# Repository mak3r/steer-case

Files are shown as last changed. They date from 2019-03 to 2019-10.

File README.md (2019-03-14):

# Steer Case
Rancher Logo Shaped case for raspberry pi with battery and other components

* CaseBase.stl - The bottom half of the case for 3D printing
* CaseTop.stl - The top half of the case for 3D printing
* Cattle Case.f3z - The Fusion 360 archive with complete history of the design
* powerboost.brd - The Powerboost board in eagle cad format
* steer.dxf - The Rancher Labs logo ready for extrusion
* tests/ - Various printable test components and openscad files for generating the testmodels

## BOM
* 6 pieces of wire - about 10 cm in length each
* Assorted connectors
  * [Female crimp pins](https://www.pololu.com/product/1930)
  * [1x3 Connector housings](https://www.pololu.com/product/1902)
  * Also I used 1-1x1 and 1-1x2 housing to split the LBO connection from the power wires(search pololu or your favorite electronics vendor)
  * Molex headers and wire housings. [Like these connectors](https://www.mouser.com/Search/Refine?Keyword=538-08-55-0111) and [these housings](https://www.mouser.com/ProductDetail/Molex/22-01-2035?qs=%2Fha2pyFadujIEQkzoGlzi6OdgxxLl5ZwtIU0IZrEPkY%3D)

*I picked up the following from Adafruit but you can get them other places too.*
* [Raspberry Pi 3 - Model B+ - 1.4GHz Cortex-A53 with 1GB RAM](https://www.adafruit.com/product/3775)
* [PowerBoost 1000 Charger - Rechargeable 5V Lipo USB Boost @ 1A - 1000C](https://www.adafruit.com/product/2465)
* [Breadboard-friendly SPDT Slide Switch](https://www.adafruit.com/product/805)
* [Lithium Ion Battery - 3.7v 2000mAh](https://www.adafruit.com/product/2011)
* [0.1" 2x20-pin Strip Right Angle Female Header](https://www.adafruit.com/product/2823)
* [Break-away 0.1" 36-pin strip right-angle male header](https://www.adafruit.com/product/1540)

## Basic Assembly
1. Print the case top and bottom. 
1. Prepare 3 wires for the switch and add connectors. *Note: I found that I needed to use 1 of the molex type connectors for the switch and used a standard 1x3 2.54mm connector for the other end.*
1. Prepare the other 3 wires and connect a 1x3 connector on one end and a 1x2 and a 1x1 on the other ends.
1. Solder a strip of 6 of the right angle male headers to the underside of the powerboost with the open ends facing into the board. The pins should span between Vs and 5v
1. Connect 1-2x20 right angle female header to the Raspberry Pi GPIO - this allows us to keep a low profile
1. Glue the switch into the bottom of the case
1. Conect the switch cable (all 3 wires between 2 1x3 headers - one is molex) to the Vs/EN/GND of the powerboost
1. Connect the other cable with the 1x3 header to the 5v/GND/LBO on the powerboost
1. Connect the 5v and GND wires to pins 4 and 6 on the Raspberry Pi
1. Connect the LBO pin to Pin 12 (or any GPIO you choose) on the Raspberry Pi
1. Glue the switch to the case (you don't have to but I found it's easier to keep in place with a dot of glue)
1. Connect the other side of the Vs/EN/GND cable to the switch
1. Place the battery in the steer head
1. Connect the battery
1. Power off it it is powered on
1. Insert an SD card into the Raspberry Pi. Be sure you can access the OS before closing the case. 
1. Insert the Raspberry Pi into the case base
1. Close it up

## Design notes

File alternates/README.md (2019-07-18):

# CaseTop-see-pi.stl
Designed with a thinner layer near the RaspberryPi insert.
Print with a clear filament to see through the top to the Rpi device.

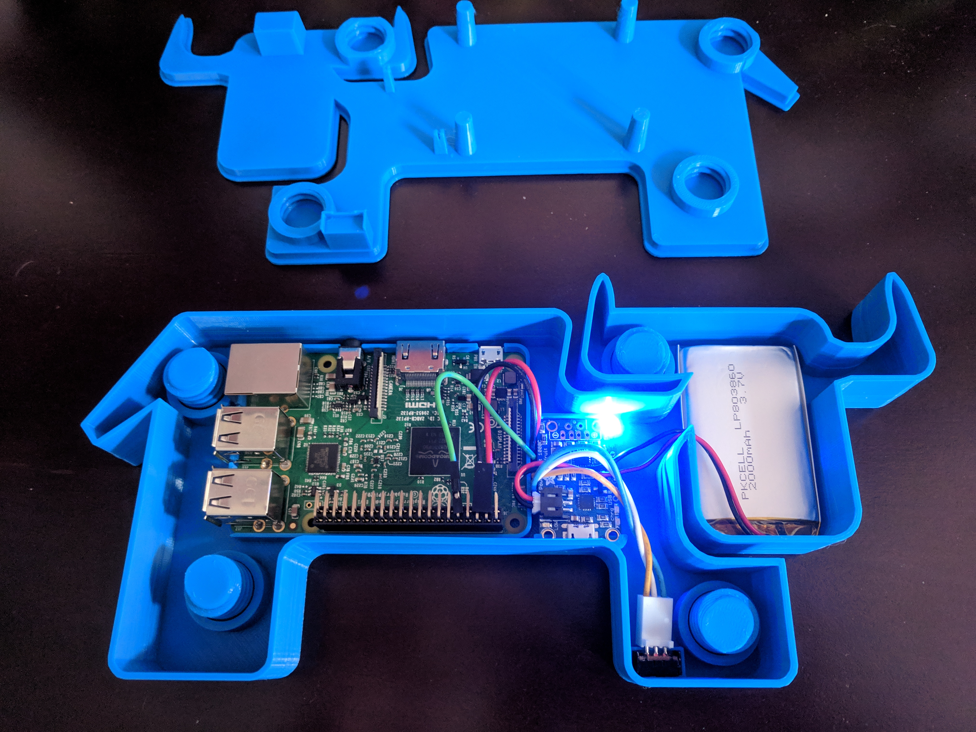
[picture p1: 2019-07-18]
images/powered_on.jpg

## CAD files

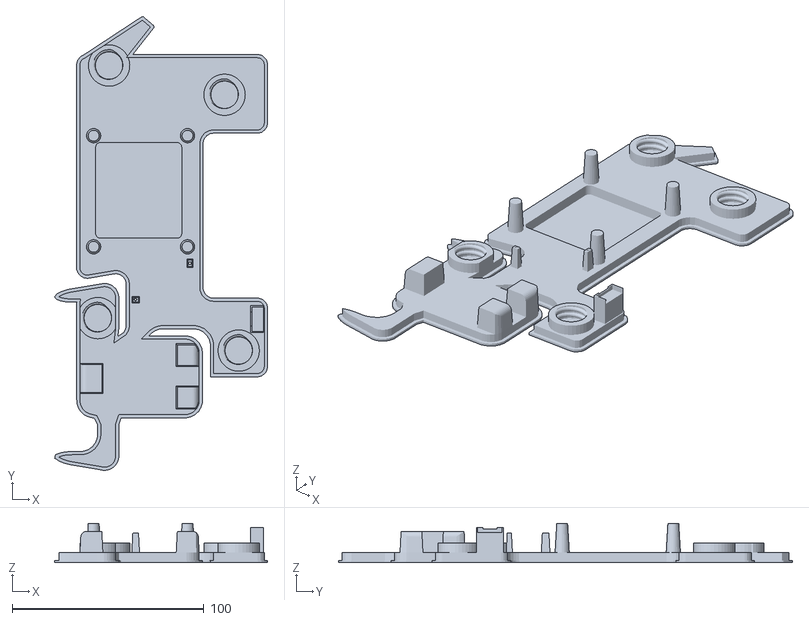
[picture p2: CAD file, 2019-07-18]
alternates/CaseTop-see-pi.stl
111.2 x 237.0 x 20.5

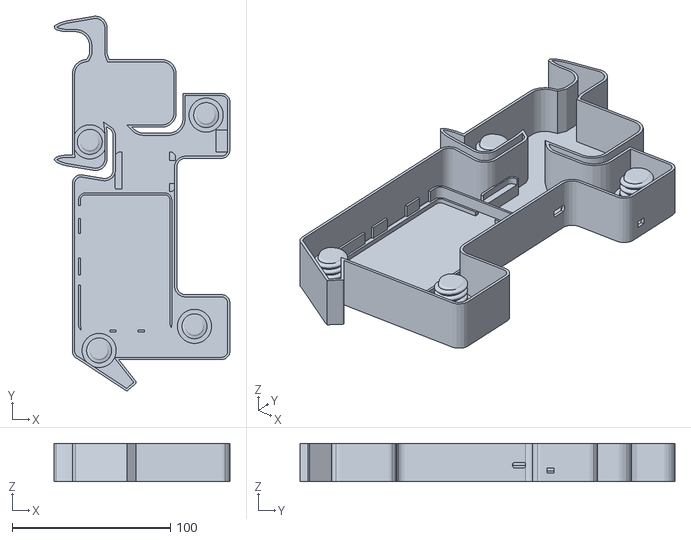
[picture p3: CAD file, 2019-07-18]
CaseBase.stl
111.2 x 237.0 x 24.3

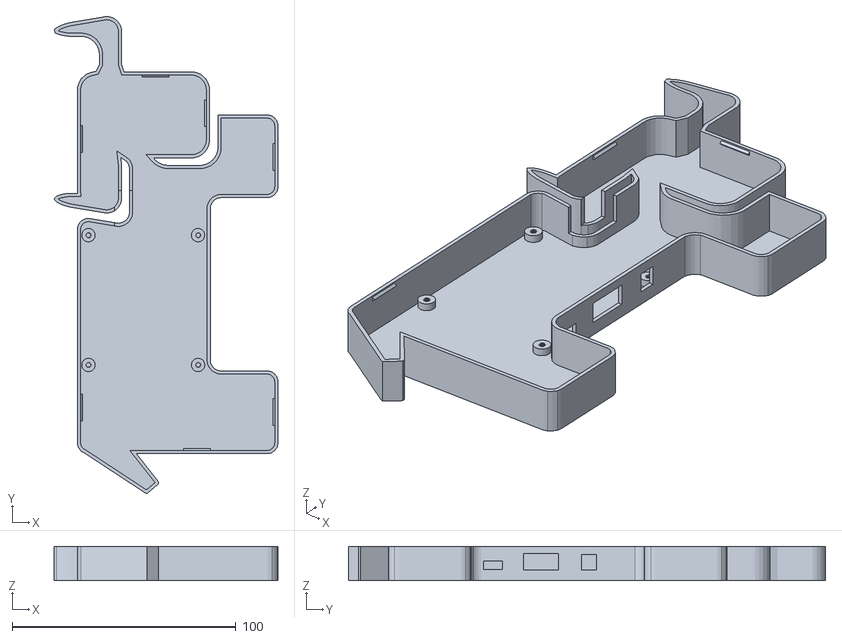
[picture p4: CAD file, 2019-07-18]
plug-in/RPi3Aplus/Base.stl
100.1 x 213.3 x 15.3

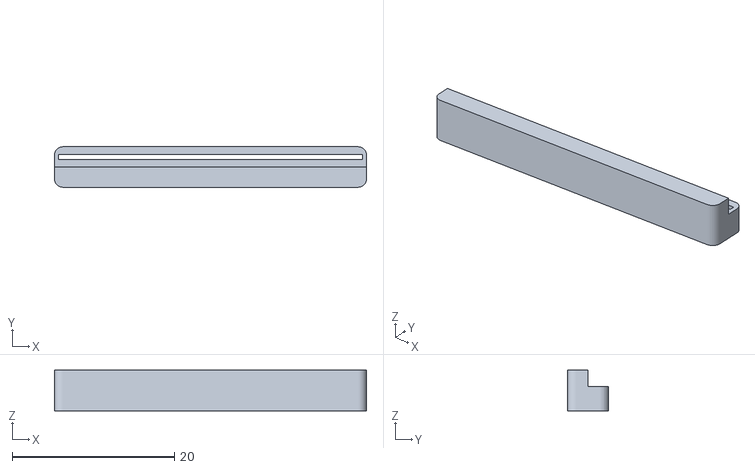
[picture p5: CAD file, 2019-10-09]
plug-in/RPi3Aplus/RevB/UPS spacer.stl
38.5 x 5.00 x 5.00

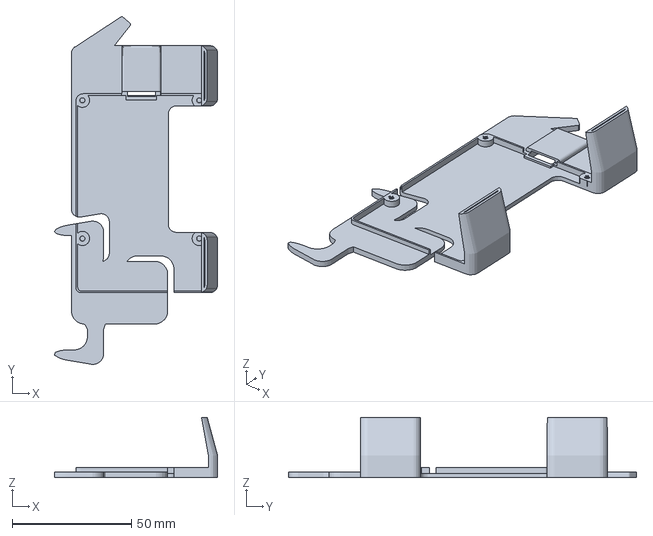
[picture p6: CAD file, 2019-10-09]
plug-in/StandingCase/StandingCase.zip.amf
68.5 x 146.0 x 25.2 mm

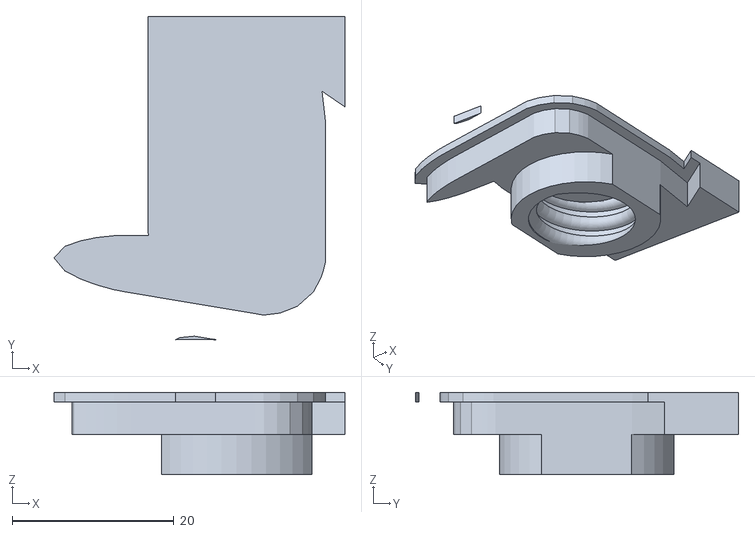
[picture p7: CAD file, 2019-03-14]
tests/case-top-thread-test.stl
36.0 x 40.0 x 10.2

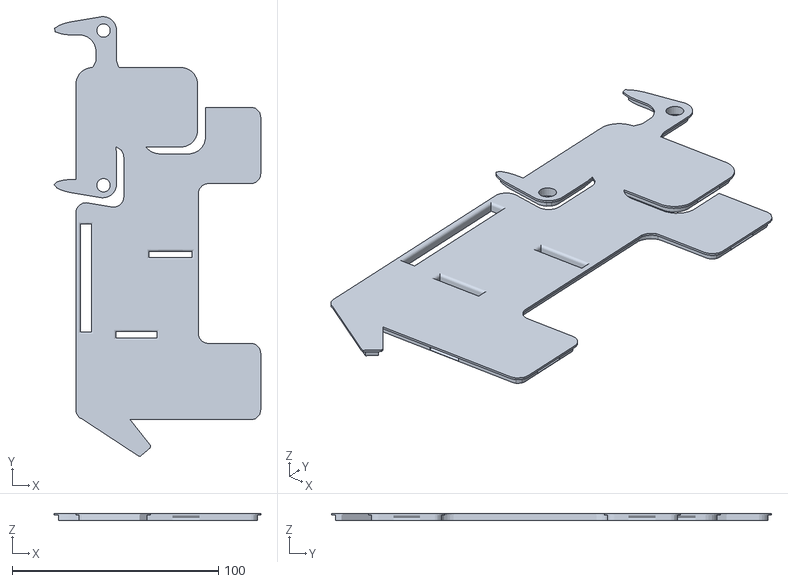
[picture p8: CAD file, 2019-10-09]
plug-in/RPi3Aplus/RevB/Top.stl
100.1 x 213.3 x 3.25

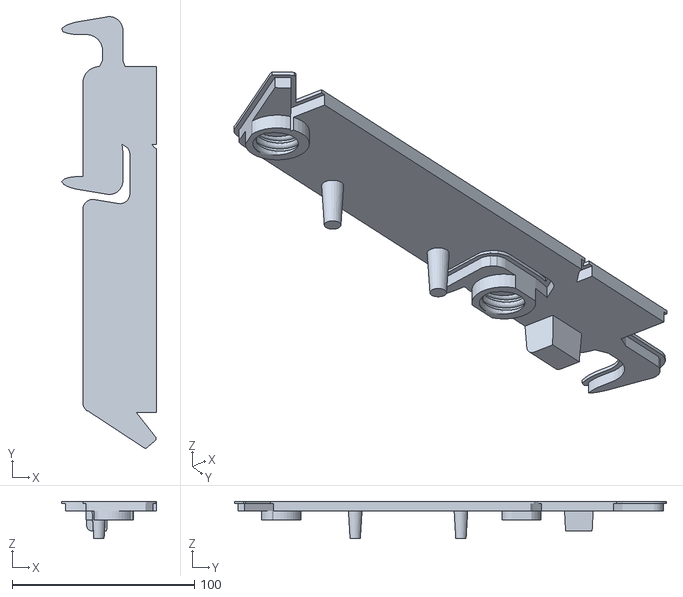
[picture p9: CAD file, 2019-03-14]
tests/case-top-half-test.stl
52.0 x 237.0 x 20.5

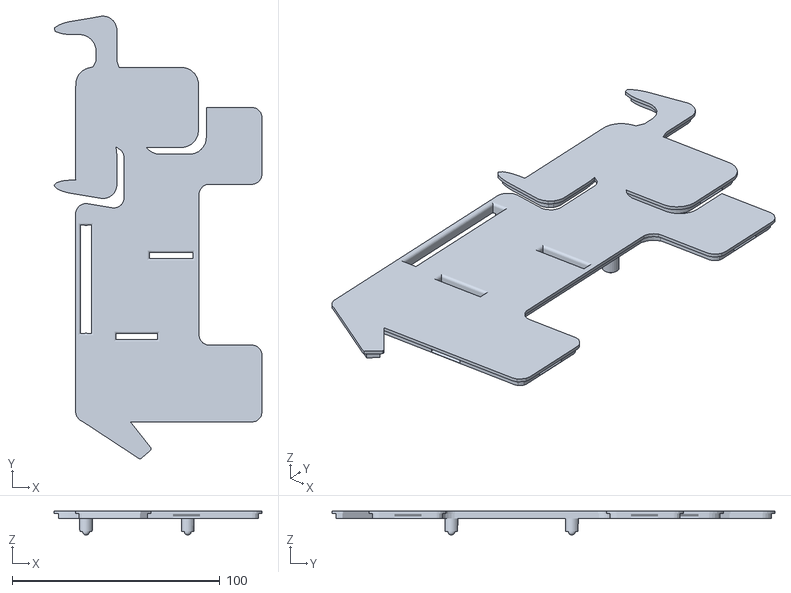
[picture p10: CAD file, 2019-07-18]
plug-in/RPi3Aplus/Top.stl
100.1 x 213.3 x 11.5

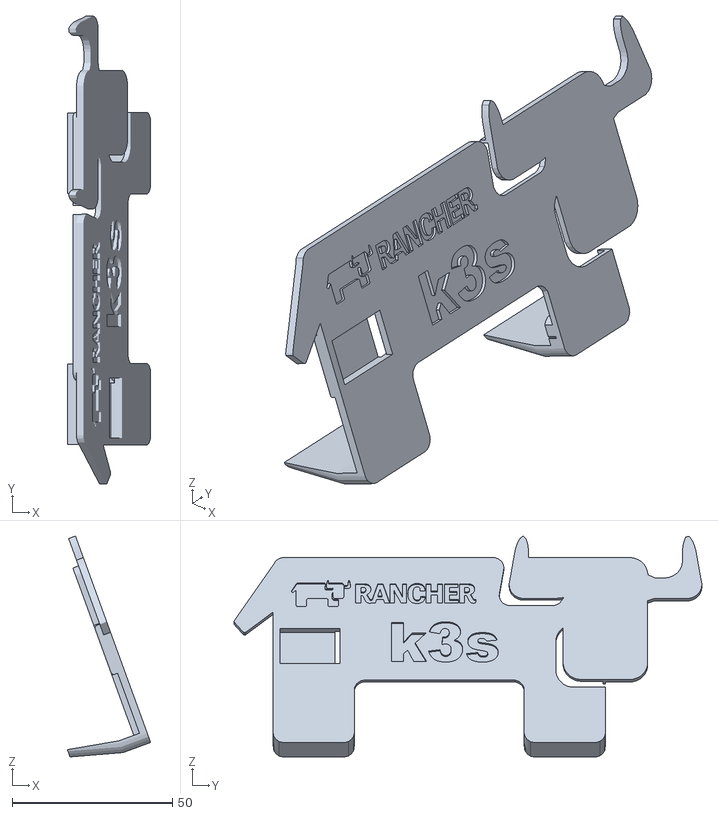
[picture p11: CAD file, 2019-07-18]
plug-in/StandingCase/StandingCase-Shapeways.stl
26.0 x 146.0 x 68.9

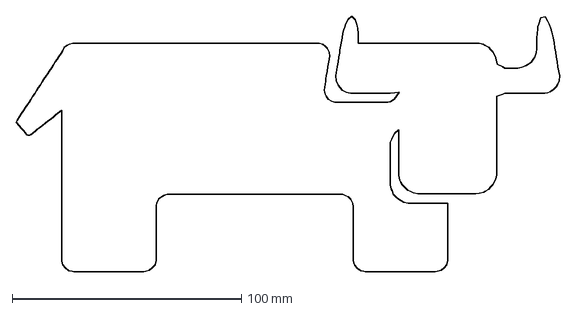
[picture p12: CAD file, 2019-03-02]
steer.dxf
237.0 x 111.2 mm

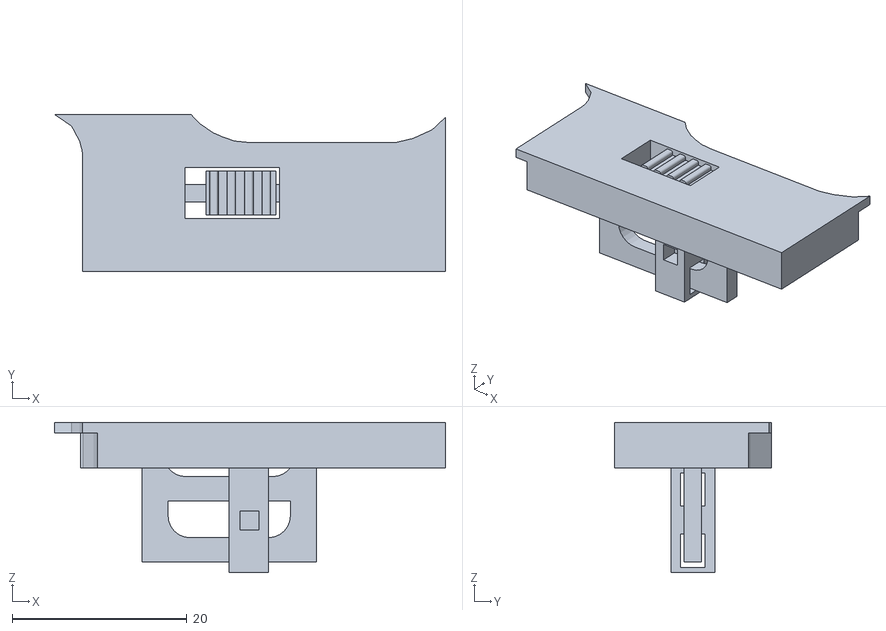
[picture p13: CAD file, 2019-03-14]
tests/case-top-test.stl
44.8 x 18.0 x 17.2

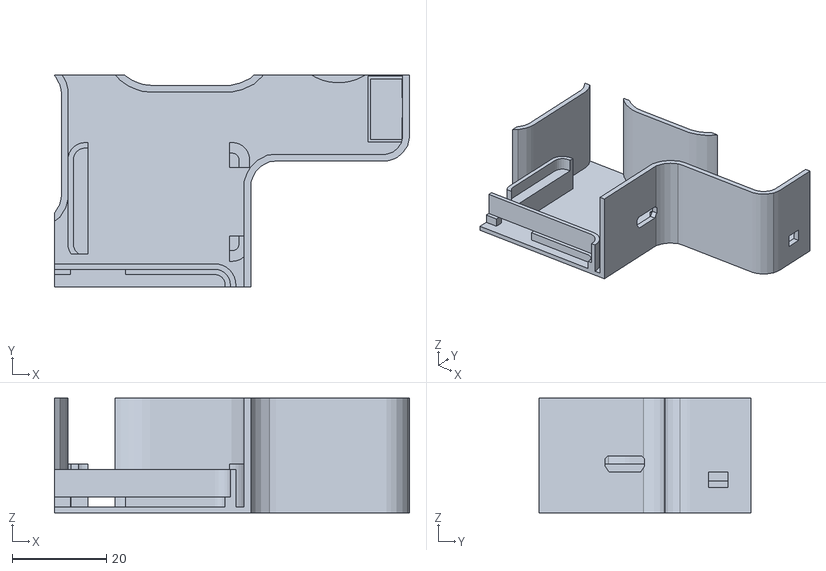
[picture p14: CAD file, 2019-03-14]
tests/switch-boost.stl
75.3 x 45.0 x 24.3

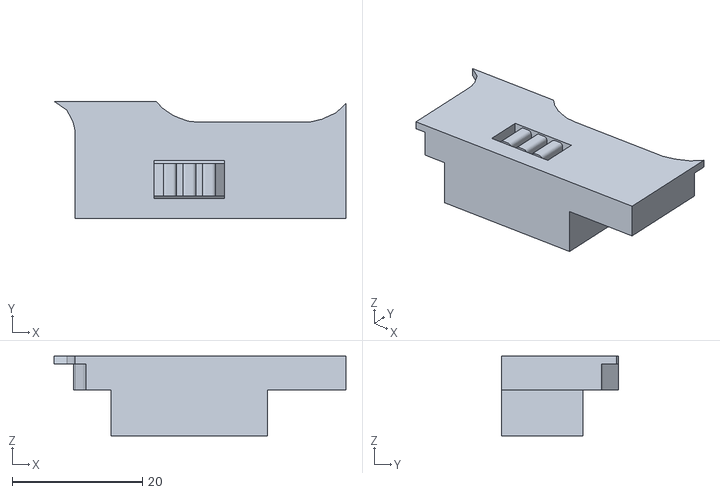
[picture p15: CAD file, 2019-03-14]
tests/switch-test.stl
44.8 x 18.0 x 12.2

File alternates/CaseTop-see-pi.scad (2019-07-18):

module window() {
    difference() {
    rotate([180,0,0])
    import("../CaseTop.stl");

        hull() {
            bxht=25.3;

            a=[-20,8];
            translate([a[0],a[1],-bxht])
            cylinder(d=5,h=bxht,$fn=20);

            b=[20,8];
            translate([b[0],b[1],-bxht])
            cylinder(d=5,h=bxht,$fn=20);

            c=[-20,-37];
            translate([c[0],c[1],-bxht])
            cylinder(d=5,h=bxht,$fn=20);

            d=[20,-37];
            translate([d[0],d[1],-bxht])
            cylinder(d=5,h=bxht,$fn=20);
        }

    }
}

module test() {
    rotate([180,0,0])
    import("../CaseTop.stl");

    #hull() {
        bxht=25.3;

        a=[-20,8];
        translate([a[0],a[1],-bxht])
        cylinder(d=5,h=bxht,$fn=20);

        b=[20,8];
        translate([b[0],b[1],-bxht])
        cylinder(d=5,h=bxht,$fn=20);

        c=[-20,-37];
        translate([c[0],c[1],-bxht])
        cylinder(d=5,h=bxht,$fn=20);

        d=[20,-37];
        translate([d[0],d[1],-bxht])
        cylinder(d=5,h=bxht,$fn=20);
    }
}

//test();
window();

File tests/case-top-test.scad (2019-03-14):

module tophalftest() {
    difference() {
        import("CaseTop.stl");
        #translate([8,-60,3])
        cube([70,200,30]);
    }
}
module coretest() {
    difference() {
        import("CaseTop.stl");
        #translate([8,-60,3])
        cube([70,200,30]);
        #translate([-35,-90,3])
        cube([50,130,30]);
    }
}

module threadtest() {
    difference() {
        import("CaseTop.stl");
        #translate([-8,-60,3])
        cube([100,200,30]);
        #translate([-35,-90,3])
        cube([50,150,30]);
        #translate([-50,100,3])
        cube([50,150,30]);
    }
}

module switchtest() {
    difference() {
        import("CaseTop.stl");
        translate([-48,-130,3])
        cube([120,200,30]);
        translate([35,40,3])
        cube([50,150,30]);
        translate([-60,70,3])
        cube([50,150,30]);
        translate([-10,90,3])
        cube([80,50,30]);
    }
}

switchtest();

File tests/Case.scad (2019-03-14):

module switchtop() {
    intersection() {
        import("CaseTop.stl");
        translate([50,70,-10])
        cube([20,20,50]);
    }
}

module switchbottom() {
    intersection() {
        import("CaseBase.stl");
        translate([50,70,-10])
        cube([20,20,50]);
    }
}

module switchandboost() {
    intersection() {
        import("CaseBase.stl");
        translate([-8,44,-10])
        cube([80,45,50]);
    }
}

module lightpipestop() {
    intersection() {
        import("CaseTop.stl");
        #translate([-8,39,-10])
        cube([80,50,50]);
    }
}


lightpipestop();
//switchtop();
//switchbottom();
//switchandboost();

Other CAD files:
CaseTop.stl
plug-in/RPi3Aplus/BaseConfig.3mf
plug-in/StandingCase/StandingCase.stl
tests/switch-top.stl
tests/part.scad
plug-in/RPi3Aplus/RPi3Aplus.f3z
tests/ScrewTight-test.stl
tests/light-pipes-top.stl
tests/part.stl
tests/switch-base.stl

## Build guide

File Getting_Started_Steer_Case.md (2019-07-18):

# GETTING STARTED WITH THE STEER CASE

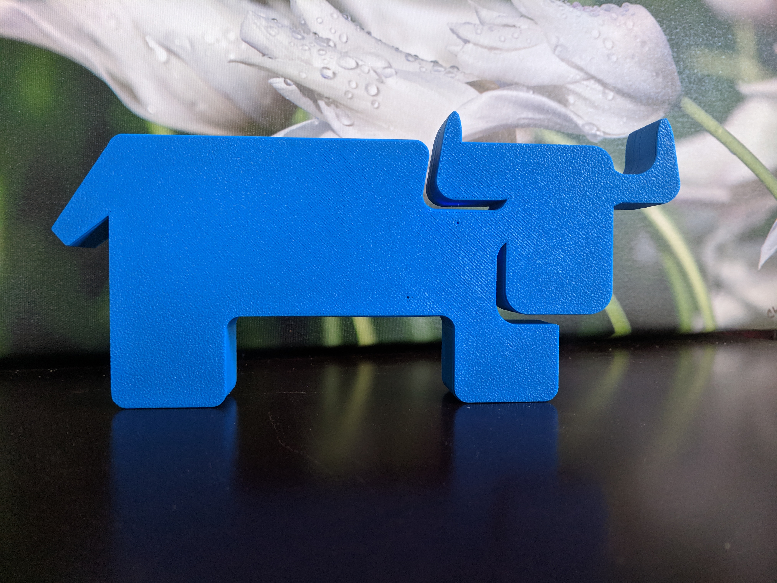
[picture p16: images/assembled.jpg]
Assembled Assembled Steer Case


## There are a few things to do before you turn it on. 

1. If it is on, turn it off.
1. Setup your network
    1. Open the case and carefully lift out the RaspberryPi. It is best to lift it from the left side where the USB and Ethernet ports are.
    1. On the bottom right is the SD card. Slide it out of the RaspberryPi and insert it into a computer using a card reader.
    1. The mounted device will contain a directory called boot. Inside boot, there is a file called `wpa_supplicant.conf`. 
    1. *Open `wpa_supplicant.conf` and add your WiFi SSID and passphrase to the appropriate section.*
    1. Save the file
    1. Unmount the SD card
    1. Insert the SD card back into the RaspberryPi
    1. Slide the right side of the RaspberrPi with the SD card into the case first making sure the SD Card goes into the opening.
    1. Secure the RaspberryPi in the case base.
    1. Re-assemble the top - if you want to.

## Power Up
1. Turn on the device.
1. ssh into the device with 
    * hostname: k3s-base
    * user: pi 
    * password: raspberry
1. K3s is already running.
    * `k3s kubectl get nodes` 

--- 

## ABOUT THE COMPONENTS

### Battery - IMPORTANT
The RaspberryPi inside the Steer Case is powered by a Lithium Polymer (LiPo) battery. The battery and components inside the steer case are equiped with overcharge and discharge protection units however it remains important to *understand the risks and be safe when using LiPo batteries*. Please read about lipo safety online. For example http://thedronegirl.com/2015/02/07/lipo-battery/. If you need to replace your battery, I recommend replacing with the same unit from Adafruit: https://www.adafruit.com/product/2011

The Powerboost can power the RaspberryPi at the same time that the battery is charging. Powerboost documentation indicates that you should *ALWAYS HAVE A LIPO BATTERY PLUGGED INTO THE POWERBOOST WHEN YOU CONNECT A MINI USB CABLE*. Meaning if you don't have a battery plugged in then use the RaspberryPi micro USB power port directly. 

If you are not operating the devices for long periods (a week or more), it is recommended to unplug the LiPo battery from the Powerboost (blue) circuit board.

### Operating System
The RaspberryPi is running a Raspbian Operating System. This is a variant of Debian designed for the RaspberryPi and usese the apt package manager. It is important to shutdown the operating system before turning off power to the device. This will prevent data coruption and the possibility of completely destroying the SD card. When logged into the device.

### Contents
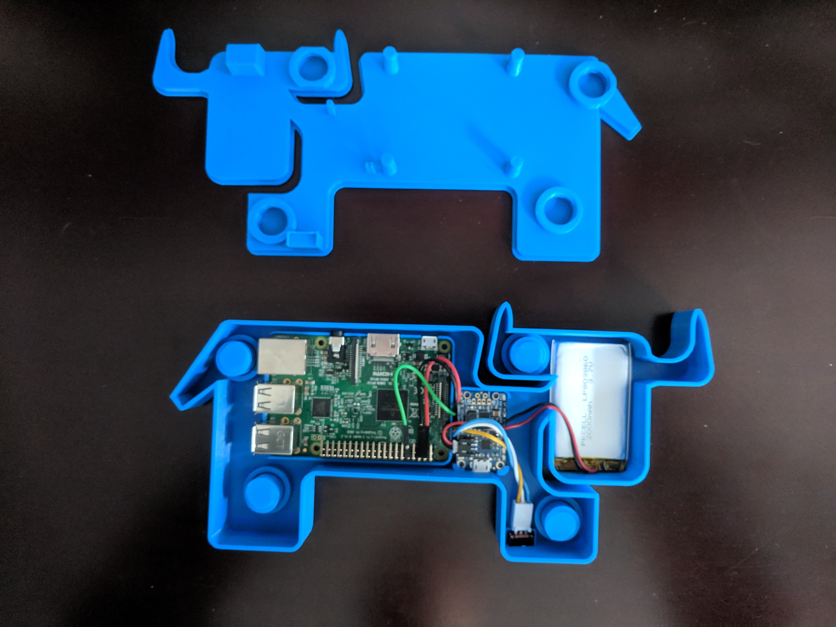
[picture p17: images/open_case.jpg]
Open Case Open Steer Case

Inside the Steer Case are 4 main components and some wiring.
* RaspberryPi (SBC)
* Powerboost (similar to the circuitry found in battery packs used to rechard mobile devices)
* SPDT switch
* LiPo battery (2000 mAh)

--- 

## GENERAL OPERATION
With a charged battery, switch the unit on. There is a switch on the right leg of the steer case. With the case top on, two LEDs are visible through holes in the top. Both lights are in the body near the front of the steer. The light nearer to the top of the case is the blue LED from the powerboost and indicates power is on. It is possible that this light is on but the RaspberryPi is not (see the section `Lights on the RaspberryPi`). Nearer the belly of the steer is a channel for the red LED of the Powerboost. If this light is on, you should immediately plugin the device *OR* shutdown the RaspberryPi and power off the entire device. (see the section `Operating System`)
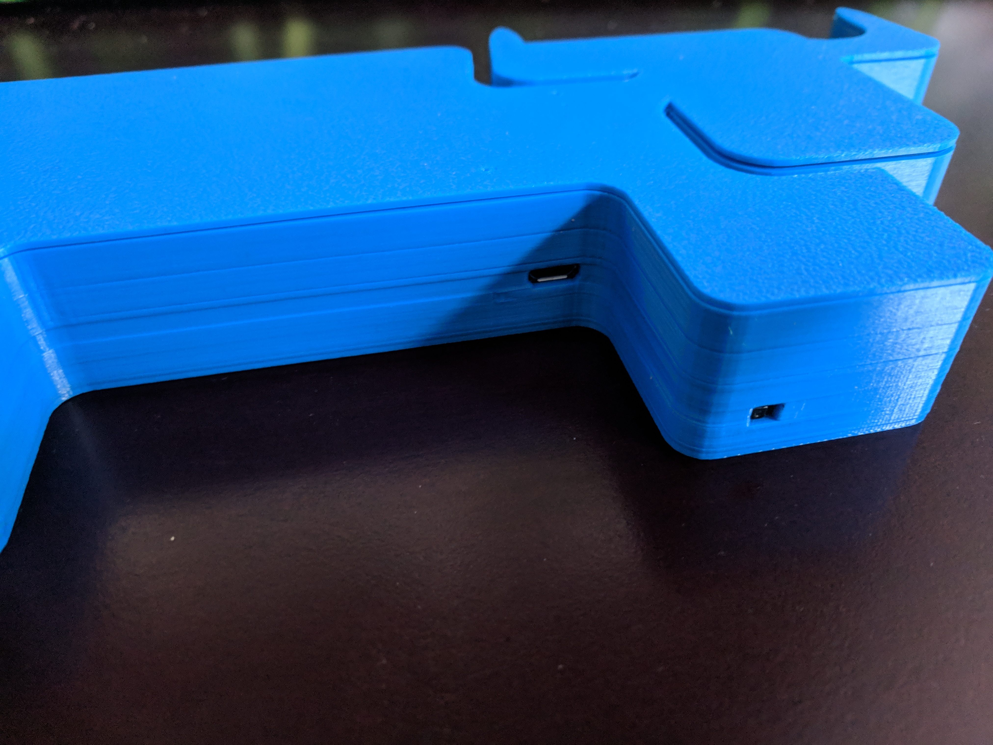
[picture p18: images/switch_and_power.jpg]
Switch and Power Switch and Power locations


### Charging
The Steer Case is designed to be charged with the case closed if desired. Underneath the belly of the steer near the front leg is a micro USB port for charging. Using quality cables for charging will insure the longest lifetime of the components inside. 
When the top of the case is off, you will notice 4 lights on the chargin unit. The blue LED indicates that the device is on. The orange LED indicates that the device is charging. The green LED indicates that the battery is completely charged (only displays when the device is turned off). The red LED indicates a low battery.

### Lights on the RaspberryPi
When the top of the case is off, you will see two lights on the RaspberryPi. The red LED indicates that the device is powered. The orange LED indicates disk activity. If the Red LED is flickering it may be an indication of a heavy draw on the battery. The RaspberryPi is designed to power down if it cannot draw enough current to operate properly.

### Opening the Case
On the bottom of the case are 4 bolts. The nature of 3D printing allows the bolts (and their corresponding nuts) to be printed right into the case so they cannot be lost. They are designed to be easy to open and close with a screwdriver or a dime or whatever you have in your pocket at the time. Don't overtighten the bolts. Simply tighten until the top of the case is flush. Due to the design, there are some areas of the case top which may not be flush when all of the screws are fully tightened.

### Production Process
The steer case was printed on a RepRap style 3D printer - a printer which was originally designed with the idea that it could print parts used by the printer itself. A sort of recursive printer if you will. Due to the nature of 3D printing you will find imperfections in the model such as wisps of plastic, "shadows" of surface variation and bits material from the print bed surface. More about the process can be gleaned at https://medium.com/@mabrams_46032/building-the-edge-case-c4a6efa4cb0c. In addition, the printable files are available https://github.com/mak3r/steer-case.

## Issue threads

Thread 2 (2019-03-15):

LBO connection to rpi causes LBO light to stay lit.

mak3r, 2019-03-15:
When LBO is connected to rpi pin 12 GPIO18, the LBO light comes on. The light comes on regardless of the state of the battery.

Initial research into this issue indicates that it may need to be connected to a pin that is pulled high in order for the light to remain off.
https://forums.adafruit.com/viewtopic.php?f=19&t=87713&p=441641&hilit=powerboost+lbo+raspberrypi#p441641
https://raspberrypi.stackexchange.com/questions/51479/gpio-pin-states-on-powerup

Initial testing for moving this to pin 24 (GPIO08) looks like it may resolve the issue

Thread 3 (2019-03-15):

Battery is loose in case

mak3r, 2019-03-15:
The original design intended to have the PowerBoost at the nose end of the head. Without it, the battery only has the press fit section near the top. Use another press fit extrusion or other method to secure the battery better.

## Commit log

2019-02-24 initial test stl for cattle pi case rev A
    [cattle-pi-BaseSampleComponents.stl]
2019-02-25 updated base screw lock
    [cattle-pi-BaseSampleComponents-v12.stl]
2019-02-25 updated gap in captive screw
    [cattle-pi-BaseSampleComponents-v15.stl]
2019-02-25 added 3 more screws. moved pi fitting
    [cattle-pi-BaseSampleComponents-v19.stl]
2019-02-26 updated captive screw design
    [cattle-pi-BaseSampleComponents-v23.stl]
2019-03-02 base taller walls, beginning of top
    [CaseTop.stl, Cattle Case v33.iges, ScrewTight-test.stl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]
2019-03-02 setup the top to have a lip as broad as the case base
    [CaseTop.stl, steer.dxf]
2019-03-02 top test
    [case-top-test.scad, case-top-test.stl]
2019-03-03 updated case top threading
    [CaseTop.stl, Cattle Case v33.iges, case-top-test.scad]
2019-03-03 updated case top pressure extrusions
    [CaseTop.stl, case-top-test.stl]
2019-03-03 cleanup threads on top
    [CaseTop.stl, case-top-test.stl]
2019-03-03 updated battery pressure extrusion
    [CaseTop.stl]
2019-03-03 tests updated, added
    [case-top-half-test.stl, case-top-test.scad, case-top-thread-test.stl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]
2019-03-04 updated with switch mechanism in top.
    [CaseTop.stl]
2019-03-04 added switch test
    [case-top-test.scad, switch-test.stl]
2019-03-05 switch mods
    [CaseTop.stl]
2019-03-06 modified switch from cantelever to box
    [CaseTop.stl, switch-test.stl]
2019-03-07 move the switch to the foot and cable connect it to headers rather than solder it on.
    [Case.scad, CaseBase.stl, CaseTop.stl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]
2019-03-07 move the switch to the foot and cable connect it to headers rather than solder it on. top stltest
    [Case.scad, switch-top.stl]
2019-03-07 slightly bigger box
    [CaseBase.stl, CaseTop.stl]
2019-03-07 open switch hole slightly larger
    [Case.scad, Case.stl, CaseBase.stl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]
2019-03-08 make top a little deeper
    [Case.scad, CaseTop.stl, switch-top.stl]
2019-03-08 first pass to include powerboost 1000c
    [Case.scad, CaseBase.stl, switch-boost.stl]
2019-03-08 update for usb mini power port spacing
    [CaseBase.stl, switch-boost.stl]
2019-03-08 added more space for the switch top to seat properly
    [Case.scad, CaseTop.stl, switch-top.stl]
2019-03-09 first pass full top
    [CaseTop.stl]
2019-03-10 light pipes top case test added
    [Case.scad, light-pipes-top.stl]
2019-03-10 repaired light pipes
    [CaseTop.stl, light-pipes-top.stl]
2019-03-13 updated base to move the spacing for some Pi components over by 4mm
    [CaseBase.stl]
2019-03-13 added the latest fusion 360 archive. cleaned up all but the necessary base files for Revision A
    [Case.scad, Case.stl, Cattle Case v57.stl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]
2019-06-20 Rev b (#4)
    * added an alternates directory for modifications that are transient to specific use cases
    * added config file for see thru - still needs tweeking. Updated case top to have more space for upright connectors. Added test scenario for moving cutter box around in CaseTop-see-pi.scad. Created s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
    * Added a getting started guide for sharing the steer case fully loaded with others.
    * the light is green not white
    * Updated case top - moved space for upright connectors to the belly. It had been imporoperly located at the top of the steer.
    * updated battery saftey info
    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
    [Base.stl, BaseConfig.3mf, CaseBase.stl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]
2019-07-18 initial release of the standing case
    [StandingCase-Shapeways.stl, StandingCase.stl]
2019-10-09 added print configs for StandingCase. added RPI3APlus Rev B changes.
    [StandingCase.zip.amf, Top.stl, UPS spacer.stl]
